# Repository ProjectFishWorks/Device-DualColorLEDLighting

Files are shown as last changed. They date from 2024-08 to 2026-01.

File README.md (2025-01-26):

# Device-LED Lighting Control

The LED Lighting control device allows for control of the blue and white tank LEDs. The device uses two MEAN WELL constant current LED drivers to power the two series strings of eight LEDs each. A 10V PWM dimming signal provided using the node controller to the drivers to allow for day-night routines and manual control from the web app.

## Hardware

The provide the required 10V PWM signal to the LED drivers, first a zener diode is used to create a 10V rail from the 24V rail. Next this 10V is switched by the Node Controller using NPN transistor. Two channels are used, one for the white LEDs and one for the blue LEDs. A two channel relay module is used to switch the AC power being provided to the LED drivers since the drivers can not fully turn off using the dimming signal. The relays and the node controller are housed in a plastic enclosure the top of the tank next to the LED drivers.

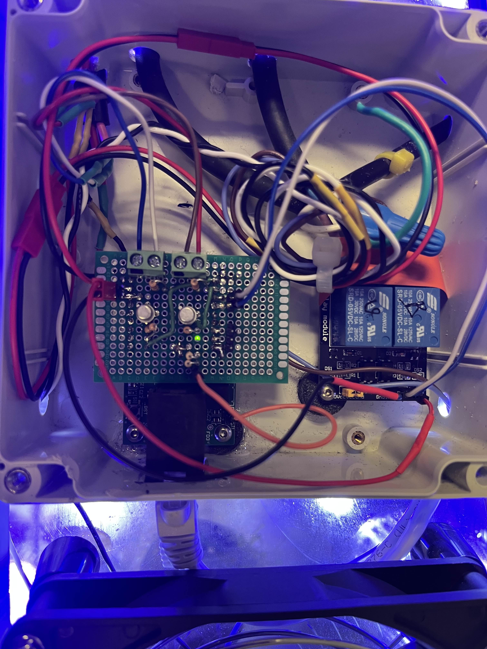
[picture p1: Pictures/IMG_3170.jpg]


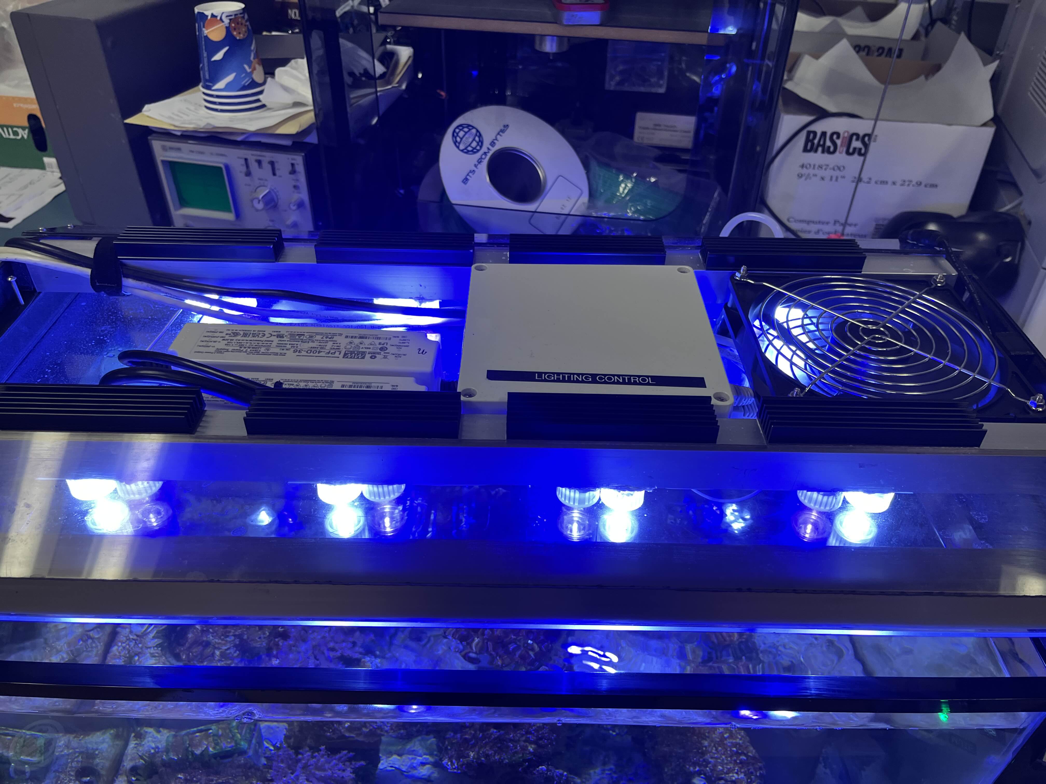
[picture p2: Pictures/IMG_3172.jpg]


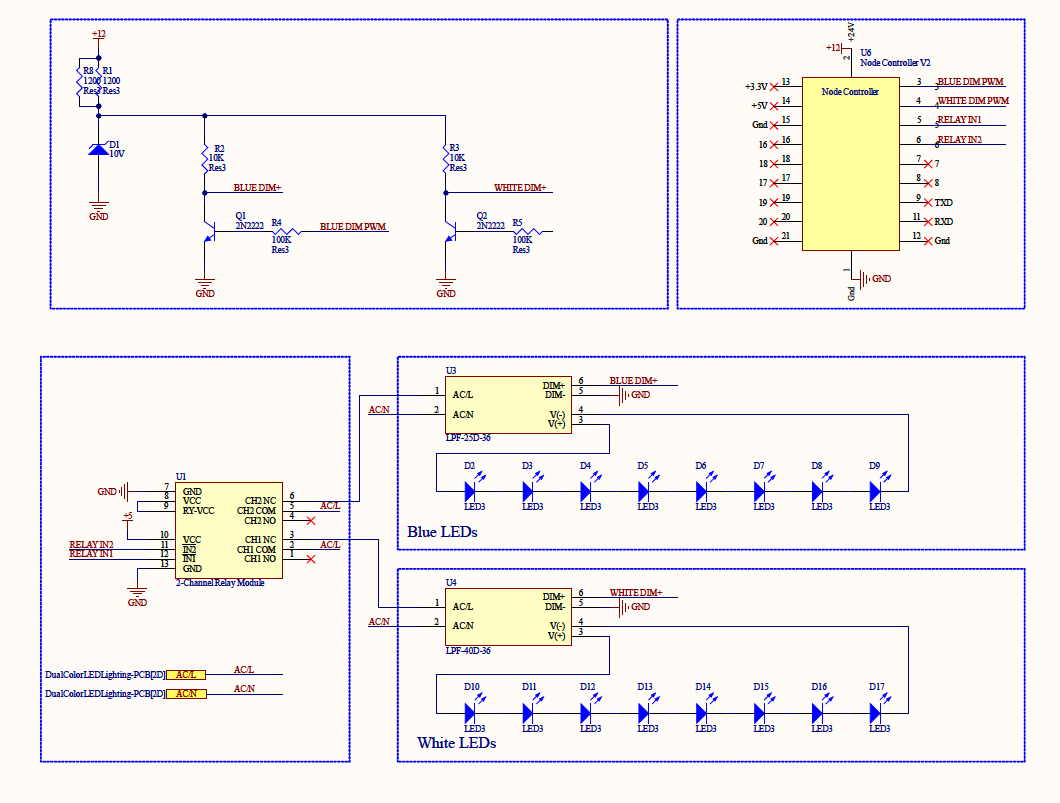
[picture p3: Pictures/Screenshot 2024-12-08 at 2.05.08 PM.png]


## Firmware

Current firmware only supports a demo day lighting loop. Future versions would need to support a full day night cycle invloving a RTC 

## Message IDs and Formats

| Parameter | Message ID | Data Format |
| --- | --- | --- |
|Dawn Demo Loop Time | 0x0A02 | Time in seconds
|Dusk Demo Loop Time | 0x0A03 | Time in seconds
|Sunrise Demo Loop Time | 0x0A04 | Time in seconds
|Sunset Demo Loop Time | 0x0A05 | Time in seconds
|Noon Demo Loop Time | 0x0A06 | Time in seconds
|Night Demo Loop Time | 0x0A07 | Time in seconds
|Blue Only Max Intensity | 0x0A08 | integer % 0 to 100
|Max White Intensity | 0x0A0E | integer % 0 to 100
|Max Blue Intensity | 0x0A0F | integer % 0 to 100
|Current White Intensity | 0x0A09 | interger PWM 0 to 255
|Current Blue Intensity | 0x0A0A | interger PWM 0 to 255
|Override White Intensity | 0x0A0C | interger PWM 0 to 255
|Override Blue Intensity | 0x0A0D | interger PWM 0 to 255

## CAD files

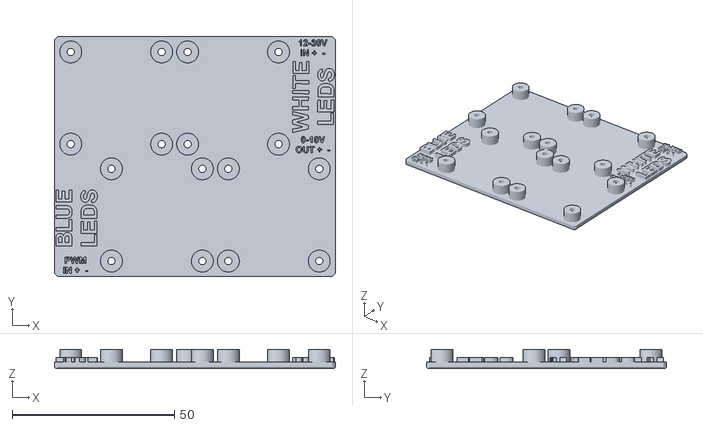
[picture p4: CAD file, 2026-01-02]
3D Models/Module Bracket v4.stl
86.5 x 74.0 x 6.00

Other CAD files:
3D Models/Lid Assembly v15.f3z

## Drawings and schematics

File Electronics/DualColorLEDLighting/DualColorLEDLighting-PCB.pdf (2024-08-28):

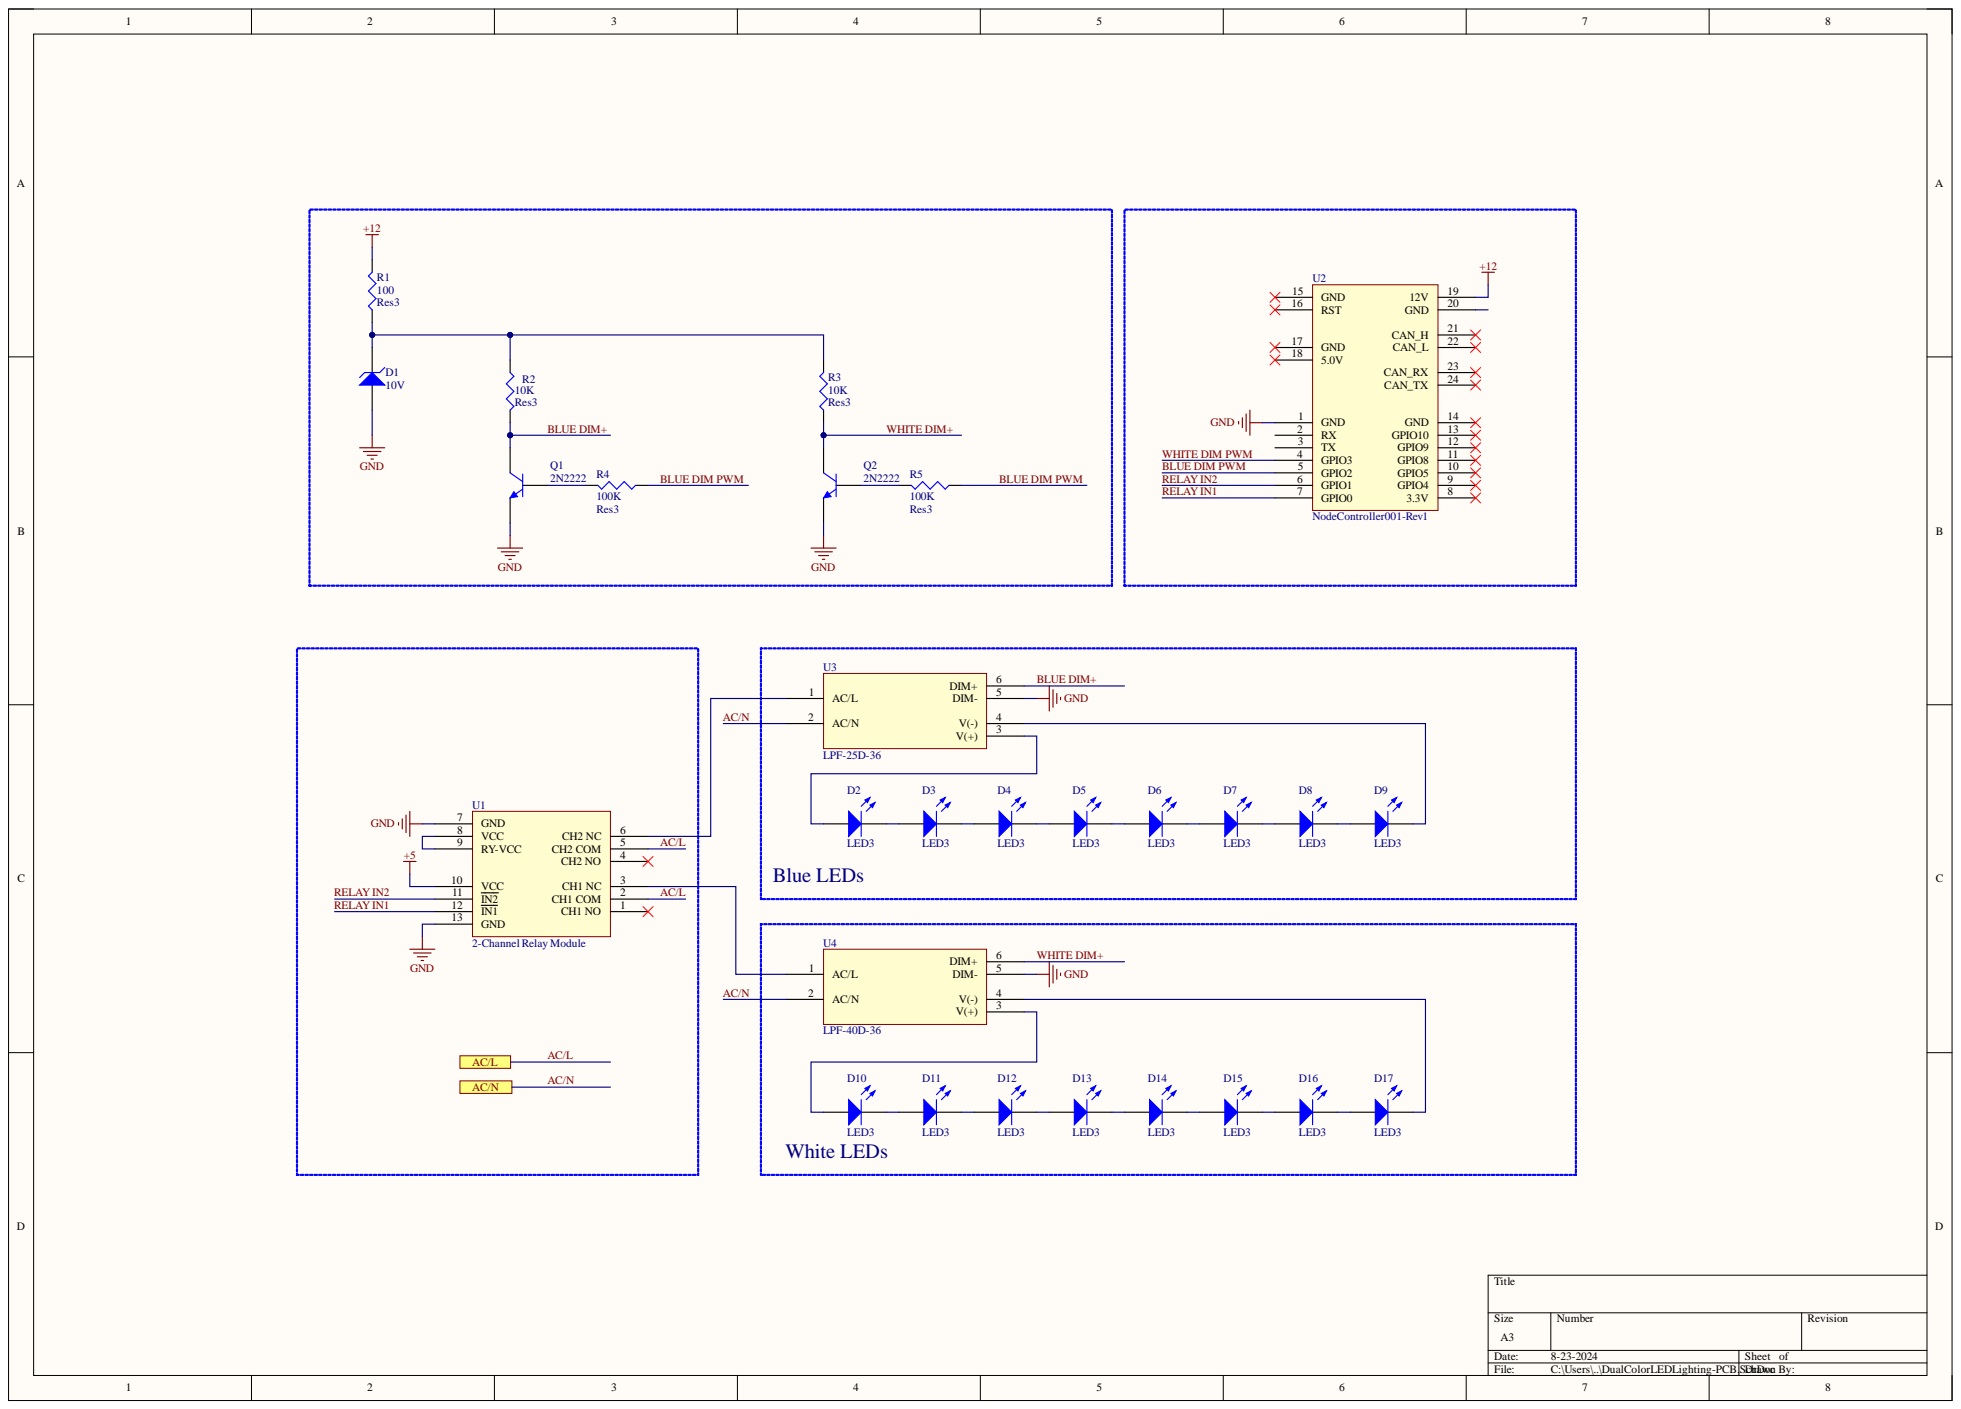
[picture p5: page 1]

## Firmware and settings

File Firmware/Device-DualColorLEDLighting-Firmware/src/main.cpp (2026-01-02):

#include <Arduino.h>
#include <NodeControllerCore.h>
#include <Wire.h>
#include <SPI.h>
#include <time.h>
#include <Adafruit_MCP4728.h>
#include "DFRobot_GP8403.h"

// Insert UNIX Time below when flashing firmware
// What is current UNIX time for testing Jan 1, 2026 10:09:00 PM UTC?
#define TimeSet 1767305485
//--------------------------------------------- put #define statements here: ----------------------------------------------------

// #define debuging
// #define debugingTime // comment out to remove time debuging

// #define usingAdafruit_MCP4728
// #define usingDFRobot_GP8403
// #define using_2X_DFRobot_GP8403
#define usingPWM_to_0to10V

//  RELAY logic, change if inverted logic
#define RELAY_ON 1
#define RELAY_OFF 0

#ifdef usingDFRobot_GP8403
// create an instance DFRobot_GP8403 of DAC using the Wire library
DFRobot_GP8403 DFRobot_GP8403_1(&Wire, 0x5F); // instance of the DAC at I2C address 0x5F
DFRobot_GP8403 DFRobot_GP8403_2(&Wire, 0x60); // instance of the DAC at I2C address 0x60
#define WHITE_1_DAC_DFRobot 0                 // DAC channel for WHITE_1
#define WHITE_2_DAC_DFRobot 0                 // DAC channel for WHITE_2
#define BLUE_1_DAC_DFRobot 1                  // DAC channel for BLUE_1
#define BLUE_2_DAC_DFRobot 1                  // DAC channel for BLUE_2
int MAX_DAC = 10000;                          // maximum DAC output value for 10V range
int DAC_OFF = 0;                              // value to turn off the DAC output
#endif

#ifdef usingAdafruit_MCP4728
// Adafruit_MCP4728 DAC object
Adafruit_MCP4728 MCP12bitDAC; //  create the MCP4728 object 12 bits of resolution = 4096 steps, so MAX_DAC = 4095
int MAX_DAC = 4095;           //  this can be changed if there is a different resolution than 12bit
int DAC_OFF = MAX_DAC;        //  change this to 0 if the DAC is not inverted
#endif

#ifdef usingPWM_to_0to10V
// PWM to 0-10V variables
#define WHITE_1_PWM_PIN 0 // PWM pin for WHITE_1
#define WHITE_2_PWM_PIN 1 // PWM pin for WHITE_2
#define BLUE_1_PWM_PIN 2  // PWM pin for BLUE_1
#define BLUE_2_PWM_PIN 3  // PWM pin for BLUE_2

#define PWM_FREQUENCY 1000                // PWM frequency IN HZ
#define PWM_RESOLUTION 12                 // PWM resolution in bits
int MAX_DAC = pow(2, PWM_RESOLUTION) - 1; // maximum PWM value based on resolution
int DAC_OFF = 0;                          // value to turn off the PWM output

#define WHITE_CHANNEL_1 0
#define WHITE_CHANNEL_2 1
#define BLUE_CHANNEL_1 2
#define BLUE_CHANNEL_2 3
#endif

// USE int FOR I2C PIN DEFINITIONS
int I2C_SDA = 2;
int I2C_SCL = 3;

// define the node ID and message IDs
#define BASESTATION_ID 0x00                         // 0
#define NODE_ID 0xA1                                // 161
#define UNIX_TIME_MESSAGE_ID 2000                   // 2000
#define UPDATE_TIMEZONE_OFFSET_MESSAGE_ID 2001      // 2001
#define DAWN_MINUTES_MESSAGE_ID 25060               // 0xA00
uint64_t dawnMinutes = 30;                          // variable to store the dawn minutes message data
#define DAWN_HOURS_MESSAGE_ID 25061                 // 0xA01
uint64_t dawnHours = 9;                             // variable to store the dawn hours message data
#define DUSK_MINUTES_MESSAGE_ID 25062               // 0xA02
uint64_t duskMinutes = 30;                          // variable to store the dusk minutes message data
#define DUSK_HOURS_MESSAGE_ID 25063                 // 0xA03
uint64_t duskHours = 21;                            // variable to store the dusk hours message data
#define SUNRISE_MINUTES_MESSAGE_ID 25064            // 0xA04
uint64_t sunriseMinutes;                            // variable to store the sunrise minutes message data
#define SUNRISE_HOURS_MESSAGE_ID 25065              // 0xA05
uint64_t sunriseHours = 11;                         // variable to store the sunrise hours message data
#define SUNSET_MINUTES_MESSAGE_ID 25066             // 0xA06
uint64_t sunsetMinutes;                             // variable to store the sunset minutes message data
#define SUNSET_HOURS_MESSAGE_ID 25067               // 0xA07
uint64_t sunsetHours = 19;                          // variable to store the sunset hours message data
#define HIGH_NOON_MINUTES_MESSAGE_ID 25068          // 0xA08
uint64_t highNoonMinutes;                           // variable to store the high noon minutes message data
#define HIGH_NOON_HOURS_MESSAGE_ID 25069            // 0xA09
uint64_t highNoonHours = 13;                        // variable to store the high noon hours message data
#define NIGHT_TIME_MINUTES_MESSAGE_ID 25070         // 0xA0A
uint64_t nightTimeMinutes = 30;                     // variable to store the night time minutes message data
#define NIGHT_TIME_HOURS_MESSAGE_ID 25071           // 0xA0B
uint64_t nightTimeHours = 22;                       // variable to store the night time hours message data
#define BLUE_1_MAX_INTENSITY_MESSAGE_ID 25072       // 0xA0C
uint64_t blue_1_MaxIntensity;                       // variable to store the blue_1 max intensity message data
float blue_1_MaxIntensity_float;                    // variable to store the blue_1 max intensity message data
#define BLUE_2_MAX_INTENSITY_MESSAGE_ID 25073       // 0xA0D
uint64_t blue_2_MaxIntensity;                       // variable to store the blue_2 max intensity message data
float blue_2_MaxIntensity_float;                    // variable to store the blue_2 max intensity message data
#define WHITE_1_MAX_INTENSITY_MESSAGE_ID 25074      // 0xA0E
uint64_t white_1_MaxIntensity;                      // variable to store the white_1 max intensity message data
float white_1_MaxIntensity_float;                   // variable to store the white_1 max intensity message data
#define WHITE_2_MAX_INTENSITY_MESSAGE_ID 25075      // 0xA0F
uint64_t white_2_MaxIntensity;                      // variable to store the white_2 max intensity message data
float white_2_MaxIntensity_float;                   // variable to store the white_2 max intensity message data
#define CURRENT_WHITE_1_MESSAGE_ID 25076            // 0xA10
uint64_t currentWhite_1_Intensity;                  // variable to store the current white_1 intensity message data
float currentWhite_1_Intensity_float;               // variable to store the current white_1 intensity message data
#define CURRENT_WHITE_2_MESSAGE_ID 25077            // 0xA11
uint64_t currentWhite_2_Intensity;                  // variable to store the current white_2 intensity message data
float currentWhite_2_Intensity_float;               // variable to store the current white_2 intensity message data
#define CURRENT_BLUE_1_MESSAGE_ID 25078             // 0xA12
uint64_t currentBlue_1_Intensity;                   // variable to store the current blue_1 intensity message data
float currentBlue_1_Intensity_float;                // variable to store the current blue_1 intensity message data
#define CURRENT_BLUE_2_MESSAGE_ID 25079             // 0xA13
uint64_t currentBlue_2_Intensity;                   // variable to store the current blue_2 intensity message data
float currentBlue_2_Intensity_float;                // variable to store the current blue_2 intensity message data
#define MANUAL_OVERRIDE_SWITCH_MESSAGE_ID 25080     // 0xA14
bool manualOverrideSwitch = false;                  // variable to store the manual override switch message data
#define OVERRIDE_WHITE_1_INTENSITY_MESSAGE_ID 25081 // 0xA15
uint64_t overrideWhite_1_Intensity;                 // variable to store the override white_1 intensity message data
float overrideWhite_1_Intensity_float;              // variable to store the override white_1 intensity message data
#define OVERRIDE_WHITE_2_INTENSITY_MESSAGE_ID 25082 // 0xA16
uint64_t overrideWhite_2_Intensity;                 // variable to store the override white_2 intensity message data
float overrideWhite_2_Intensity_float;              // variable to store the override white_2 intensity message data
#define OVERRIDE_BLUE_1_INTENSITY_MESSAGE_ID 25083  // 0xA17
uint64_t overrideBlue_1_Intensity;                  // variable to store the override blue_1 intensity message data
float overrideBlue_1_Intensity_float;               // variable to store the override blue_1 intensity message data
#define OVERRIDE_BLUE_2_INTENSITY_MESSAGE_ID 25084  // 0xA18
uint64_t overrideBlue_2_Intensity;                  // variable to store the override blue_2 intensity message data
float overrideBlue_2_Intensity_float;               // variable to store the override blue_2 intensity message data
#define MIN_WHITE_VALUE_MESSAGE_ID 25085            // 0xA19
u_int64_t minWhiteValue = 0;                        // variable to store the min white value message data
float minWhiteValue_float;                          // variable to store the min white value message data
#define MIN_BLUE_VALUE_MESSAGE_ID 25086             // 0xA1A
uint64_t minBlueValue = 0;                          // variable to store the min blue value message data
float minBlueValue_float;                           // variable to store the min blue value message data

#ifdef usingAdafruit_MCP4728
// colored and numbered names for the DAC channels to take values from 0-4095
#define WHITE_1_DAC MCP4728_CHANNEL_A
#define WHITE_2_DAC MCP4728_CHANNEL_B
#define BLUE_1_DAC MCP4728_CHANNEL_C
#define BLUE_2_DAC MCP4728_CHANNEL_D
#endif

// RELAY pins
#define BLUE_RELAY 18
#define WHITE_RELAY 19

#define sendMqttMessageUpdateUI 5000 // frequency of sending LED intensity messages to the App
#define updateLEDs 100               // Delay time in milliseconds
#define MessageGap 1000              // Delay time in milliseconds

// Globals for time keeping
char localTime[64];          // Local time string
String localTimeZone;        // "UTC+" + localTimeZoneOffset
int localTimeZoneOffset = 8; // Timezone offset
char buf_localTimeZone[8];   // Char array Buffer for timezone string
struct tm timeinfo;          // Time structure
struct timeval tv;           // Time value structure
time_t UNIXtime;             // UNIX time
int curTimeSec;              //  get the start time in seconds since midnight
int dawnStart;               //  start time of dawn in seconds since midnight
int sunriseStart;            //  start time of sunrise in seconds since midnight
int highNoonStart;           //  start time of high noon in seconds since midnight
int sunsetStart;             //  start time of sunset in seconds since midnight
int duskStart;               //  start time of dusk in seconds since midnight
int nightTimeStart;          //  start time of night time in seconds since midnight
int dawnDurationSec;         //  duration of dawn in seconds
int sunriseDurationSec;      //  duration of sunrise in seconds
int highNoonDurationSec;     //  duration of high noon in seconds
int sunsetDurationSec;       //  duration of sunset in seconds
int duskDurationSec;         //  duration of dusk in seconds
int nightTimeDurationSec;    //  duration of night time in seconds
int MIDNIGHT = 86400;        //  24 hours in seconds

// Node controller core object
NodeControllerCore core;

//--------------------------------------------- put function declarations here:----------------------------------------------------

// Callback function for received messages from the CAN bus
void receive_message(uint8_t nodeID, uint16_t messageID, uint64_t data);

// Function to set the PWM value for a given channel
void setPWM(int channel, int value);

// Function to send LED intensities to the App
void SendLEDIntensities(void *parameters);

// Function to Adjust fade the LED intensities through the daylight cycles
void LightCycles(void *parameters);

// Function to check the manual override switch
void chkmanualOverrideSwitch();

// Function to update the times and schedules of the light cycles
void updateTimes();

//-------------------------------------------------------- setup -------------------------------------------------------------------

void setup()
{
  // Initialize serial communication
  Serial.begin(115200);
  Serial.println("Initializing Serial Communication");
  Serial.println("");

  // Initialize the time keeping
  tv.tv_sec = TimeSet; // Set the time in seconds since epoch
  localTimeZone = "UTC+" + String(localTimeZoneOffset);
  localTimeZone.toCharArray(buf_localTimeZone, 8);
  setenv("TZ", buf_localTimeZone, 1);
  tzset();
  settimeofday(&tv, NULL);

  // Initialize the OneWire communication
  Wire.begin(I2C_SDA, I2C_SCL);
  Serial.println("Initializing I2C Communication");
  Serial.println("");
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
void loop()
{
}

////////////////////////////////////////////// put function definitions here:  /////////////////////////////////////////////////////////

void LightCycles(void *parameters)
{
  while (1)
  {
    delay(MessageGap);
    updateTimes();

    Serial.println("");
    Serial.println("Starting Light Cycles Function " + String(curTimeSec));
    Serial.println("");

    // Set the LEDs to off in no Light cycles are valid times

#ifdef usingDFRobot_GP8403
    DFRobot_GP8403_1.setDACOutVoltage(WHITE_1_DAC_DFRobot, DAC_OFF); //  set the WHITE_1_DAC to 0V
    DFRobot_GP8403_2.setDACOutVoltage(WHITE_2_DAC_DFRobot, DAC_OFF); //  set the WHITE_2_DAC to 0V
    DFRobot_GP8403_1.setDACOutVoltage(BLUE_1_DAC_DFRobot, DAC_OFF);  //  set the BLUE_1_DAC to 0V
    DFRobot_GP8403_2.setDACOutVoltage(BLUE_2_DAC_DFRobot, DAC_OFF);  //  set the BLUE_2_DAC to 0V
#endif

#ifdef usingAdafruit_MCP4728
    MCP12bitDAC.setChannelValue(WHITE_1_DAC, DAC_OFF); //  set the WHITE_1_DAC to DAC_OFF
    MCP12bitDAC.setChannelValue(WHITE_2_DAC, DAC_OFF); //  set the WHITE_2_DAC to DAC_OFF
    MCP12bitDAC.setChannelValue(BLUE_1_DAC, DAC_OFF);  //  set the BLUE_1_DAC to DAC_OFF
    MCP12bitDAC.setChannelValue(BLUE_2_DAC, DAC_OFF);  //  set the BLUE_2_DAC to DAC_OFF
#endif

#ifdef usingPWM_to_0to10V
    // Turn off all PWM channels
    setPWM(WHITE_CHANNEL_1, 0);
    setPWM(WHITE_CHANNEL_2, 0);
    setPWM(BLUE_CHANNEL_1, 0);
    setPWM(BLUE_CHANNEL_2, 0);
#endif

    digitalWrite(BLUE_RELAY, RELAY_OFF);  // turn off the blue relay
    digitalWrite(WHITE_RELAY, RELAY_OFF); // turn off the white relay

#ifdef debuging
    Serial.println("Blue LED off");
    Serial.println("White LED off");
    Serial.println("curTimeSec 2 = " + String(curTimeSec));
    Serial.println("");
#endif

    //-------------------------------------------------- "Dawn" -------------------------------------------------------------------

    while (curTimeSec >= dawnStart && curTimeSec < sunriseStart) // check if the current time is between dawnStart and sunriseStart
    {
      Serial.println("In Dawn Loop curTimeSec = " + String(curTimeSec));
      Serial.println("");

      delay(updateLEDs);
      updateTimes();
      chkmanualOverrideSwitch(); //  check if the manual override switch is on

      currentBlue_1_Intensity = map(curTimeSec, dawnStart, dawnStart + dawnDurationSec, 0, blue_1_MaxIntensity); //  map the current time to the start time and the duration of the dawnDurationSec
      currentBlue_2_Intensity = map(curTimeSec, dawnStart, dawnStart + dawnDurationSec, 0, blue_2_MaxIntensity); //  map the current time to the start time and the duration of the dawnDurationSec

#ifdef usingDFRobot_GP8403
      DFRobot_GP8403_1.setDACOutVoltage(BLUE_1_DAC_DFRobot, currentBlue_1_Intensity); //  set the BLUE_1_DAC to the mapped intensity
      DFRobot_GP8403_2.setDACOutVoltage(BLUE_2_DAC_DFRobot, currentBlue_2_Intensity); //  set the BLUE_2_DAC to the mapped intensity
#endif

#ifdef usingAdafruit_MCP4728
      MCP12bitDAC.setChannelValue(BLUE_1_DAC, MAX_DAC - currentBlue_1_Intensity); //  set the BLUE_1_DAC to the mapped intensity
      MCP12bitDAC.setChannelValue(BLUE_2_DAC, MAX_DAC - currentBlue_2_Intensity); //  set the BLUE_2_DAC to the mapped intensity
#endif

#ifdef usingPWM_to_0to10V
      // Set the PWM value for each channel
      setPWM(BLUE_CHANNEL_1, currentBlue_1_Intensity);
      setPWM(BLUE_CHANNEL_2, currentBlue_2_Intensity);
#endif

      if (currentBlue_1_Intensity <= minBlueValue)
      {
        digitalWrite(BLUE_RELAY, RELAY_OFF); //  turn off the blue relay
        delay(updateLEDs);
      }
      else
      {
        digitalWrite(BLUE_RELAY, RELAY_ON); //  turn on the blue relay
      }

#ifdef debuging
      Serial.println("while (curTimeSec >= dawnStart && curTimeSec < sunriseStart)");
      Serial.println("UNIXtime = " + String(UNIXtime));
      Serial.println("curTimeSec = " + String(curTimeSec));
      Serial.println("dawnDurationSec = " + String(dawnDurationSec));
      Serial.println("dawnStart = " + String(dawnStart));
      Serial.println("blue_1_MaxIntensity = " + String(blue_1_MaxIntensity));
      Serial.println("currentBlue_1_Intensity = " + String(currentBlue_1_Intensity));
      Serial.println("currentWhite_1_Intensity = " + String(currentWhite_1_Intensity));
      Serial.println("Blue relay = " + String(digitalRead(BLUE_RELAY)));
      Serial.println("White relay = " + String(digitalRead(WHITE_RELAY)));
      Serial.println("");
#endif
    }

    //----------------------------------- "Sunrise" Fade blue and white to highNoon  --------------------------------------------------
    while (curTimeSec >= sunriseStart && curTimeSec < highNoonStart)
    {
      Serial.println("In Sunrise Loop curTimeSec = " + String(curTimeSec));
      Serial.println("");

      delay(updateLEDs);
      updateTimes();
      chkmanualOverrideSwitch();

      //                     map( inputValue, low range input, high range input, low range output, high range output);
      currentBlue_1_Intensity = map(curTimeSec, sunriseStart, sunriseStart + sunriseDurationSec, minBlueValue, blue_1_MaxIntensity);
      currentBlue_2_Intensity = map(curTimeSec, sunriseStart, sunriseStart + sunriseDurationSec, minBlueValue, blue_2_MaxIntensity);
      currentWhite_1_Intensity = map(curTimeSec, sunriseStart, sunriseStart + sunriseDurationSec, minBlueValue, white_1_MaxIntensity);
      currentWhite_2_Intensity = map(curTimeSec, sunriseStart, sunriseStart + sunriseDurationSec, minBlueValue, white_2_MaxIntensity);

#ifdef usingDFRobot_GP8403
      DFRobot_GP8403_1.setDACOutVoltage(BLUE_1_DAC_DFRobot, currentBlue_1_Intensity);
      DFRobot_GP8403_1.setDACOutVoltage(BLUE_2_DAC_DFRobot, currentBlue_2_Intensity);
      DFRobot_GP8403_1.setDACOutVoltage(WHITE_1_DAC_DFRobot, currentWhite_1_Intensity);
      DFRobot_GP8403_1.setDACOutVoltage(WHITE_2_DAC_DFRobot, currentWhite_2_Intensity);
#endif

#ifdef usingAdafruit_MCP4728
      MCP12bitDAC.setChannelValue(BLUE_1_DAC, MAX_DAC - currentBlue_1_Intensity);
      MCP12bitDAC.setChannelValue(BLUE_2_DAC, MAX_DAC - currentBlue_2_Intensity);
      MCP12bitDAC.setChannelValue(WHITE_1_DAC, MAX_DAC - currentWhite_1_Intensity);
      MCP12bitDAC.setChannelValue(WHITE_2_DAC, MAX_DAC - currentWhite_2_Intensity);
#endif

#ifdef usingPWM_to_0to10V
      setPWM(BLUE_CHANNEL_1, currentBlue_1_Intensity);
      setPWM(BLUE_CHANNEL_2, currentBlue_2_Intensity);
      setPWM(WHITE_CHANNEL_1, currentWhite_1_Intensity);
      setPWM(WHITE_CHANNEL_2, currentWhite_2_Intensity);
#endif

      if (currentWhite_1_Intensity <= minWhiteValue)
      {
        digitalWrite(WHITE_RELAY, RELAY_OFF);
        delay(updateLEDs);
      }
      else
      {
        digitalWrite(WHITE_RELAY, RELAY_ON);
      }

#ifdef debuging
      Serial.println("while (curTimeSec >= sunriseStart && curTimeSec < highNoonStart)");
      Serial.println("UNIXtime = " + String(UNIXtime));
      Serial.println("curTimeSec = " + String(curTimeSec));
      Serial.println("sunriseDurationSec = " + String(sunriseDurationSec));
      Serial.println("sunriseStart = " + String(sunriseStart));
      Serial.println("blue_1_MaxIntensity = " + String(blue_1_MaxIntensity));
      Serial.println("currentBlue_1_Intensity = " + String(currentBlue_1_Intensity));
      Serial.println("currentWhite_1_Intensity = " + String(currentWhite_1_Intensity));
      Serial.println("Blue relay = " + String(digitalRead(BLUE_RELAY)));
      Serial.println("White relay = " + String(digitalRead(WHITE_RELAY)));
      Serial.println("");
#endif
    }

    //----------------------------------------------------- "HighNoon" ---------------------------------------------------------------

    while (curTimeSec >= highNoonStart && curTimeSec < sunsetStart)
    {
      Serial.println("In HighNoon Loop curTimeSec = " + String(curTimeSec));
      Serial.println("");

      delay(updateLEDs);
      updateTimes();
      chkmanualOverrideSwitch();

      currentBlue_1_Intensity = blue_1_MaxIntensity;
      currentBlue_2_Intensity = blue_2_MaxIntensity;
      currentWhite_1_Intensity = white_1_MaxIntensity;
      currentWhite_2_Intensity = white_2_MaxIntensity;

#ifdef usingDFRobot_GP8403
      DFRobot_GP8403_1.setDACOutVoltage(BLUE_1_DAC_DFRobot, currentBlue_1_Intensity);
      DFRobot_GP8403_1.setDACOutVoltage(BLUE_2_DAC_DFRobot, currentBlue_2_Intensity);
      DFRobot_GP8403_1.setDACOutVoltage(WHITE_1_DAC_DFRobot, currentWhite_1_Intensity);
      DFRobot_GP8403_1.setDACOutVoltage(WHITE_2_DAC_DFRobot, currentWhite_2_Intensity);
#endif
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

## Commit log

2024-08-24 Add basic schematic
    [DualColorLEDLighting-PCB.PrjPcb, DualColorLEDLighting-PCB.SchDoc]
2024-08-28 Update relay control pins
    [DualColorLEDLighting-PCB.PrjPcb, DualColorLEDLighting-PCB.SchDoc]
2024-09-06 Added ds3231 module to sch.doc
    [DualColorLEDLighting-PCB.SchDoc]
2024-09-15 Added Relay control to demoloop
2024-09-16 Adjusted time for relays
2024-09-16 Fixed Relay delay
2024-09-20 Added demo Override and a check for the switch in demo
2024-09-20 Finished overrides but it statrs at 0 when switched
2024-09-24 Updated I2C
2024-10-12 Pin change for node v2
2024-10-14 Fixed Blue only intensity
    [main.cpp]
2024-10-17 Changed fade down blue only from if<50 to <25 off relay
2024-11-02 White PWM fixes
2024-12-08 Folder restructure
    [DualColorLEDLighting-PCB.PrjPcb, DualColorLEDLighting-PCB.SchDoc]
2024-12-08 Add updated Altuim project
    [DualColorLEDLighting-PCB 2.SchDoc, DualColorLEDLighting-PCB.PrjPcb, DualColorLEDLighting-PCB.SCHLIB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]
2024-12-11 Add 3D model
    [Lid Assembly v15.f3z]
2025-01-27 fixed sytax errors receving both UNIX message and timezone message
    [main.cpp]
2025-11-12 Added PWM to 0-10V converter support
2025-11-12 Changeed PWM pins to 0,1,2,3
2026-01-02 Added Time Preset and tested for PWM to Analog Modules
    [Module Bracket v4.stl]
2026-01-02 Fixed MaxIntensitiy defaults in setup
    [main.cpp]
